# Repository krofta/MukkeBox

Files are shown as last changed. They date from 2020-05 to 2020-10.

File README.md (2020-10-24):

# MukkeBox_Electric

This is a project made with KiCAD.
During corona virus i was pretty bored at home and started to build my own portable bluetooth speaker and this is the result.
Additional I have to more repositories for software and mechanics:  
https://github.com/krofta/MukkeBox_Mechanic  
https://github.com/krofta/MukkeBox_Software

This PCB contains:  
Charger for 1-6s LiPo Packs (configured for 4s)  TI BQ24610  
ST microcontroller to controll the whole circuit STM32F030C6Tx  
Step up to make 4s pack-voltage to constant 24V TI TPS40210
Digital audio processor ST TDA7719 with i2c interface  
2x Class D audio amplifiers TI TPA3116D2  (in 2.1 sound system configuration with 20dB gain)

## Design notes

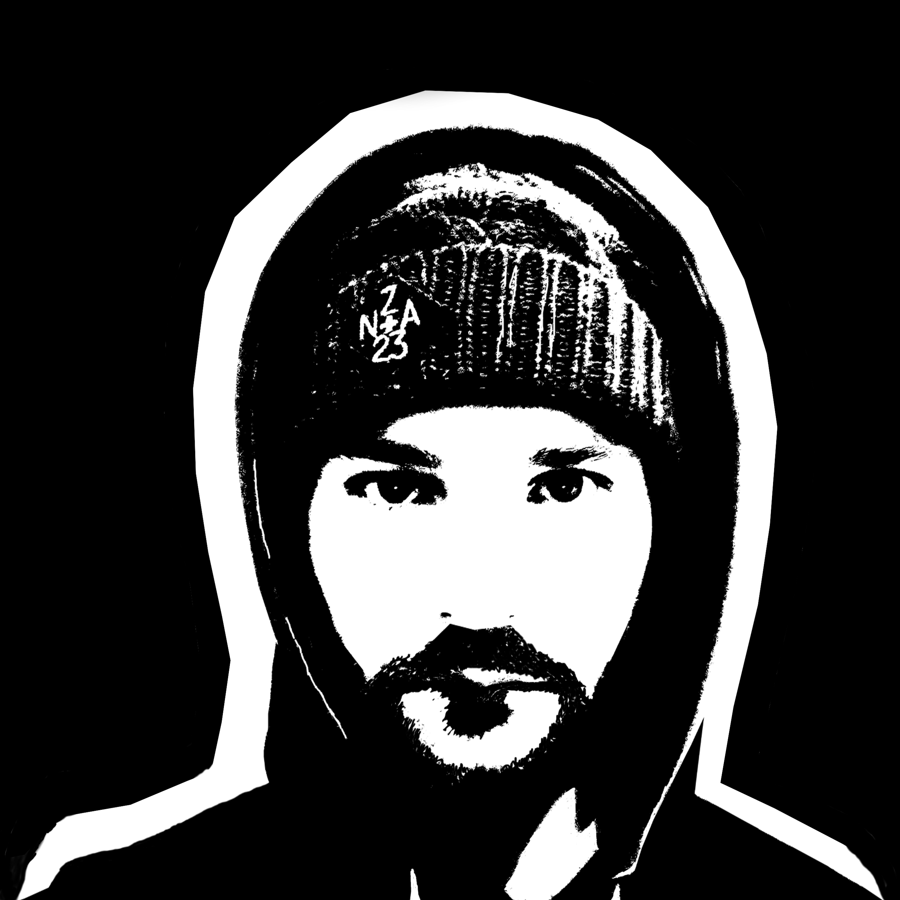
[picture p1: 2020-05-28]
IMG_50x50final.jpg

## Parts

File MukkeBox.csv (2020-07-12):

ID | Bezeichner | Gehäuse | Stückzahl | Bezeichnung | Anbieter und Referenz
1 | U301 | VQFN-24-1EP_4x4mm_P0.5mm_EP2.45x2.45mm_ThermalVias | 1 | BQ24610
2 | C311,C308 | C_0603_1608Metric_Pad1.05x0.95mm_HandSolder | 2 | 33n
3 | R302,R312,R310,R103,R104,R105,R307,R313,R315,R316,R318,R412,R413,R417,R501,R502,R505,R613,R614,R1,R301,R303,R304,R305,R15C301,R1C301,R3C301,R5C301,R7C301,R309,R201,R_201,R_202,R_203 | R_0603_1608Metric_Pad1.05x0.95mm_HandSolder | 34 | 100K
4 | Q309,Q201,Q305 | Diodes_PowerDI3333-8 | 3 | VS6412AE
5 | C307,C304,C310 | C_1210_3225Metric | 3 | 1u
6 | Q306,Q303,Q308,Q501,Q1,Q301 | SOT-23 | 6 | 2N7002
7 | R311,R106,R107,R108,R109,R119,R120,R121,R122,R124,R317,R415,R525,R615,R616,R618,R619,R620,R6,R205,R306,R19C301,R516 | R_0603_1608Metric_Pad1.05x0.95mm_HandSolder | 23 | 1K
8 | H101,H102,H103,H104,H105,H106 | MountingHole_3.2mm_M3_DIN965_Pad | 6 | MountingHole_Pad
9 | C101,C102,C103,C106,C107,C108,C109,C309,C501,C502,C504,C510,C541,C543,C544,C612,C602,C607,C608,C301,C204,C205,C302,C303,C305,C306,C312,C313,C15C301,C114,C115,C505,C506,C511,C512 | C_0603_1608Metric_Pad1.05x0.95mm_HandSolder | 35 | 100n
10 | C104,C105 | C_0603_1608Metric_Pad1.05x0.95mm_HandSolder | 2 | 20p
11 | C110,C111,C112,C113 | C_0603_1608Metric_Pad1.05x0.95mm_HandSolder | 4 | 10n
12 | C412,C211 | CP_Radial_D5.0mm_P2.50mm | 2 | 68u
13 | C507,C517,C518,C534 | C_Rect_L7.0mm_W2.5mm_P5.00mm | 4 | 1n
14 | C519,C520 | C_Rect_L7.0mm_W2.5mm_P5.00mm | 2 | 470n
15 | C521,C522,C523,C524,C526,C527,C528,C529 | C_Rect_L7.0mm_W2.5mm_P5.00mm | 8 | 220n
16 | C530,C531,C532,C_5_2,C525 | CP_Radial_D12.5mm_P5.00mm | 5 | 560u 50V
17 | D101 | LED_D3.0mm | 1 | LED_Small
18 | HS302 | Heatsink_AAVID_573300D00010G_TO-263 | 1 | 573300D00000G
19 | J101 | PinHeader_2x20_P2.54mm_Vertical | 1 | Conn_02x20_Odd_Even
20 | J102 | PinHeader_1x04_P2.54mm_Vertical | 1 | Conn_01x04
21 | J103,J104 | PinHeader_2x05_P2.54mm_Vertical | 2 | Conn_02x05_Odd_Even
22 | J301,J302 | PinHeader_2x04_P2.54mm_Vertical | 2 | Conn_02x04_Odd_Even
23 | J401 | TerminalBlock_RND_205-00045_1x02_P5.00mm_Horizontal | 1 | TB001-500-02BE CUI_Devices
24 | J501,J303 | TerminalBlock_RND_205-00047_1x04_P5.00mm_Horizontal | 2 | TB001-500-04BE CUI_Devices
25 | J602,J604,J605 | PinHeader_1x02_P2.54mm_Vertical | 3 | Conn_02x01
26 | J603 | PinHeader_2x06_P2.54mm_Vertical | 1 | Conn_02x06_Odd_Even
27 | L501,L502,L503,L504 | L_Radial_D12.0mm_P6.00mm_MuRATA_1900R | 4 | 22uH 6100-220K-RC
28 | Q307 | SOT-23 | 1 | BSS84
29 | R101,R102,R9C301 | R_0603_1608Metric_Pad1.05x0.95mm_HandSolder | 3 | 2K2
30 | R117,R118,R314,R416,R513,R518,R_FBT601,R3,R520,R521,R522,R527,R6C301,R8C301 | R_0603_1608Metric_Pad1.05x0.95mm_HandSolder | 14 | 10K
31 | R503,R203,R204 | R_0603_1608Metric_Pad1.05x0.95mm_HandSolder | 3 | 22R
32 | R504 | R_0603_1608Metric_Pad1.05x0.95mm_HandSolder | 1 | 39K
33 | R506,R507 | R_1206_3216Metric_Pad1.42x1.75mm_HandSolder | 2 | 22R
34 | R508,R509,R510,R511 | R_1206_3216Metric_Pad1.42x1.75mm_HandSolder | 4 | 8R
35 | R512,R519,R4,R5 | R_1206_3216Metric_Pad1.42x1.75mm_HandSolder | 4 | 0R
36 | R514,R610 | R_0603_1608Metric_Pad1.05x0.95mm_HandSolder | 2 | 100R
37 | R515,R526,R617 | R_0603_1608Metric_Pad1.05x0.95mm_HandSolder | 3 | DNP
38 | R523,R524 | R_0603_1608Metric_Pad1.05x0.95mm_HandSolder | 2 | 47R
39 | R602,R609 | R_0603_1608Metric_Pad1.05x0.95mm_HandSolder | 2 | 470K
40 | R_2,R2 | R_0603_1608Metric_Pad1.05x0.95mm_HandSolder | 2 | 47K
41 | R_3 | R_0603_1608Metric_Pad1.05x0.95mm_HandSolder | 1 | 422R
42 | SW501 | DIP-4_W8.89mm_SMDSocket_LongPads | 1 | DS04-254-2-02BK-SMT
43 | U101 | TO-92_Inline | 1 | LM35-LP
44 | U102 | LQFP-48_7x7mm_P0.5mm | 1 | STM32F030C6Tx_MukkeBox
45 | U503 | TSSOP-28_4.4x9.7mm_P0.65mm | 1 | TDA7719
46 | Y101 | Crystal_SMD_HC49-SD | 1 | FOXSDLF/080-20
47 | C413,C414,C411,C503,C508,C509,C536,C542,C601,C611 | CP_Radial_D4.0mm_P2.00mm | 10 | 10u
48 | F301 | Fuseholder_Cylinder-5x20mm_Schurter_0031_8201_Horizontal_Open | 1 | Fuse_Small
49 | L601,L505 | L_Bourns-SRN4018 | 2 | 10u Bourns SRN4018
50 | U602,U505 | SOT-23-6_Handsoldering | 2 | JW5026
51 | C537,C538,C539,C540,C603,C604,C605,C606,C609,C610,C613,C533,C535 | C_Rect_L7.2mm_W3.5mm_P5.00mm_FKS2_FKP2_MKS2_MKP2 | 13 | 1u
52 | J601 | PinHeader_1x03_P2.54mm_Vertical | 1 | Conn_01x03_Female
53 | TP501,TP502,TP503 | TestPoint_Pad_1.0x1.0mm | 3 | TestPoint
54 | U504 | TSOT-23-6 | 1 | AP2553AW6-7
55 | C203 | C_0603_1608Metric_Pad1.05x0.95mm_HandSolder | 1 | 100p
56 | C206 | C_0603_1608Metric_Pad1.05x0.95mm_HandSolder | 1 | 470p
57 | C207,C209 | C_1206_3216Metric | 2 | 330n
58 | C208 | C_0603_1608Metric_Pad1.05x0.95mm_HandSolder | 1 | 1u
59 | C210 | C_0603_1608Metric_Pad1.05x0.95mm_HandSolder | 1 | 220p
60 | L302 | L_Wuerth_HCI-1050 | 1 | 10u Würth 7443251000
61 | R202 | R_0603_1608Metric_Pad1.05x0.95mm_HandSolder | 1 | 20K
62 | U203 | MSOP-10-1EP_3x3mm_P0.5mm_EP1.68x1.88mm | 1 | TPS40210
63 | C314 | C_0603_1608Metric_Pad1.05x0.95mm_HandSolder | 1 | 22p
64 | D201 | TO-277B | 1 | PS1060L
65 | D301,D601 | SOT-23 | 2 | BAT54C
66 | Q302,Q304,Q310,Q311 | Diodes_PowerDI3333-8 | 4 | HSBB3103
67 | R308 | R_0603_1608Metric_Pad1.05x0.95mm_HandSolder | 1 | 10R
68 | R2C301 | R_0603_1608Metric_Pad1.05x0.95mm_HandSolder | 1 | 700K
69 | R4C301 | R_0603_1608Metric_Pad1.05x0.95mm_HandSolder | 1 | 22K
70 | R9C302 | R_0603_1608Metric_Pad1.05x0.95mm_HandSolder | 1 | 6K8
71 | RAC301,RSR301 | R_1206_3216Metric_Pad1.42x1.75mm_HandSolder | 2 | 10m
72 | U202 | StepUpModul | 1 | StepUp
73 | HS501 | Heatsink_57.9x36.8mm_4xFixation3.17mm_537-95AB | 1 | 537-95AB
74 | L301 | PQ2617BHA-330K | 1 | 22uH PQ2617BHA-220K
75 | U501 | ST_PowerSSO-36_TDA7498 | 1 | TDA7498L
76 | U502 | BK8000L | 1 | BK8000L
77 | C514,C515 | C_1210_3225Metric | 2 | 2.2u
78 | R601 | R_0603_1608Metric_Pad1.05x0.95mm_HandSolder | 1 | 3K3
79 | U103 | TO-92_Inline | 1 | MCP9700
80 | L201 | TAITEC TMPC1265HP-220MG-D | 1 | 22uH TAITEC TMPC1265HP-220MG-D
81 | REF** | WEEE-Logo_4.2x6mm_SilkScreen | 1 | WEEE-Logo_4.2x6mm_SilkScreen
82 | REF** | Symbol_KiCAD-Logo_CopperAndSilkScreenTop | 1 | KiCAD Logo
83 | R_8 | R_2512_6332Metric_Pad1.52x3.35mm_HandSolder | 1 | R012
84 | RV_1 | Potentiometer_P250 | 1 | 10K

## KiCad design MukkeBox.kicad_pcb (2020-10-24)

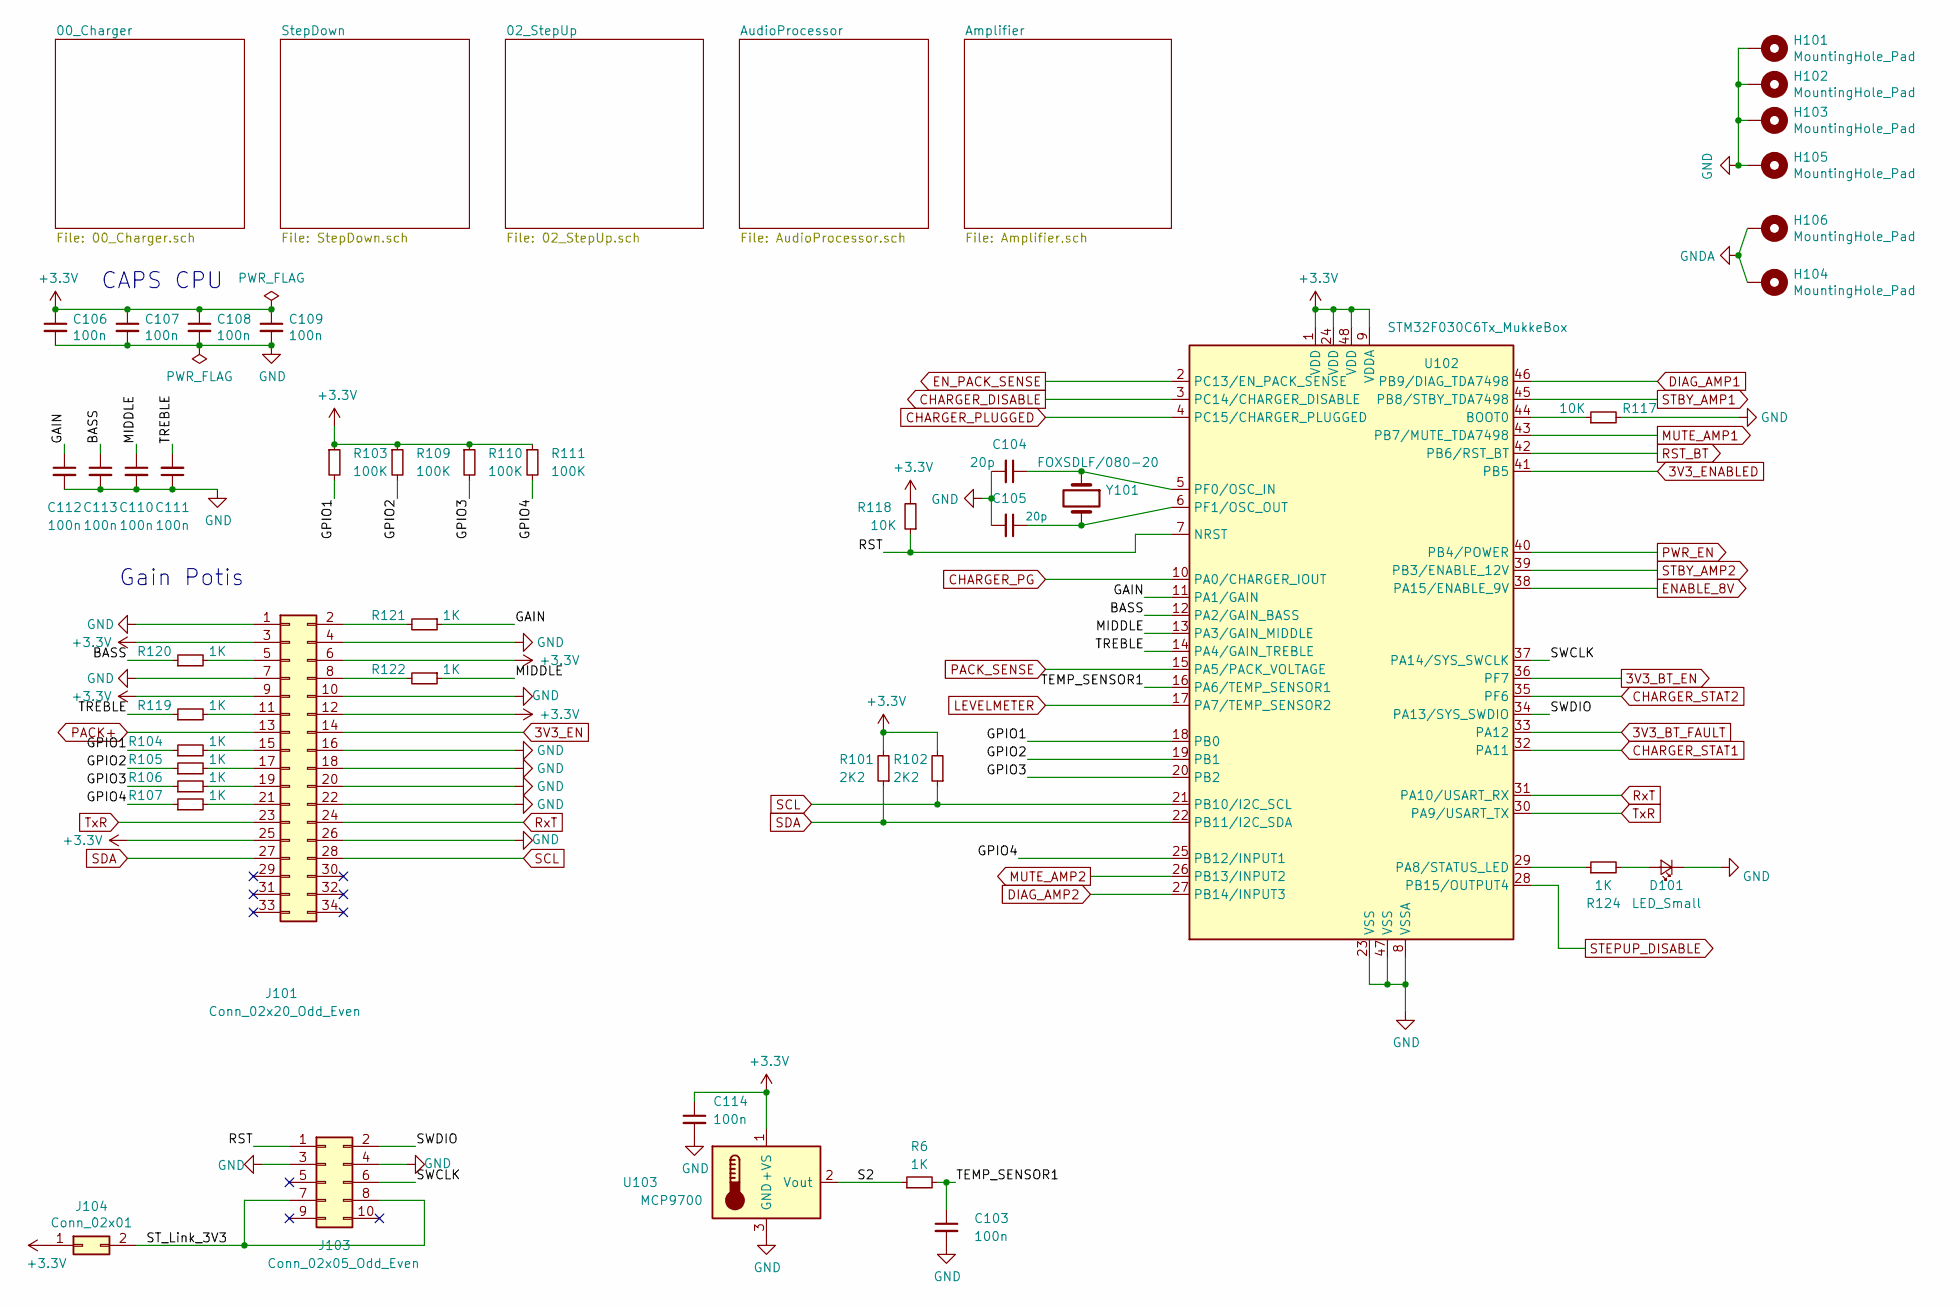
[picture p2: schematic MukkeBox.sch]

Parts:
C103, C106, C107, C108, C109, C110, C111, C112, C113, C114: 100n; C_0603_1608Metric_Pad1.05x0.95mm_HandSolder
C104, C105: 20p; C_0603_1608Metric_Pad1.05x0.95mm_HandSolder
D101: LED_Small; LED_D3.0mm
H101, H102, H103, H104, H105, H106: MountingHole_Pad; MountingHole_3.2mm_M3_DIN965_Pad
J101: Conn_02x20_Odd_Even; PinHeader_2x17_P2.54mm_Vertical
J103: Conn_02x05_Odd_Even; PinHeader_2x05_P2.54mm_Vertical
J104: Conn_02x01; PinHeader_1x02_P2.54mm_Vertical
R6, R104, R105, R106, R107, R119, R120, R121, R122, R124: 1K; R_0603_1608Metric_Pad1.05x0.95mm_HandSolder
R101, R102: 2K2; R_0603_1608Metric_Pad1.05x0.95mm_HandSolder
R103, R109, R110, R111: 100K; R_0603_1608Metric_Pad1.05x0.95mm_HandSolder
R117, R118: 10K; R_0603_1608Metric_Pad1.05x0.95mm_HandSolder
U102: STM32F030C6Tx_MukkeBox; LQFP-48_7x7mm_P0.5mm
U103: MCP9700; TO-92_Inline
Y101: FOXSDLF/080-20; Crystal_SMD_HC49-SD

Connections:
3V3_BT_EN: U102.36 (PF7); also elsewhere on the board
3V3_BT_FAULT: U102.33 (PA12); also elsewhere on the board
3V3_EN: J101.14; also elsewhere on the board
3V3_ENABLED: U102.41 (PB5); also elsewhere on the board
/BASS: C113.1, R120.1, U102.12 (PA2/GAIN_BASS)
/GAIN: C112.1, R121.1, U102.11 (PA1/GAIN)
/GPIO1: R103.2, R104.1, U102.18 (PB0)
/GPIO2: R105.1, R109.2, U102.19 (PB1)
/GPIO3: R106.1, R110.2, U102.20 (PB2)
/GPIO4: R107.1, R111.2, U102.25 (PB12/INPUT1)
/MIDDLE: C110.1, R122.1, U102.13 (PA3/GAIN_MIDDLE)
/RST: J103.1, R118.1, U102.7 (NRST)
/S2: R6.1, U103.2 (Vout)
/ST_Link_3V3: J103.7, J103.8, J104.2
/SWCLK: J103.6, U102.37 (PA14/SYS_SWCLK)
/SWDIO: J103.2, U102.34 (PA13/SYS_SWDIO)
/TEMP_SENSOR1: C103.1, R6.2, U102.16 (PA6/TEMP_SENSOR1)
/TREBLE: C111.2, R119.1, U102.14 (PA4/GAIN_TREBLE)
CHARGER_DISABLE: U102.3 (PC14/CHARGER_DISABLE); also elsewhere on the board
CHARGER_PG: U102.10 (PA0/CHARGER_IOUT); also elsewhere on the board
CHARGER_PLUGGED: U102.4 (PC15/CHARGER_PLUGGED); also elsewhere on the board
CHARGER_STAT1: U102.32 (PA11); also elsewhere on the board
CHARGER_STAT2: U102.35 (PF6); also elsewhere on the board
DIAG_AMP1: U102.46 (PB9/DIAG_TDA7498); also elsewhere on the board
DIAG_AMP2: U102.27 (PB14/INPUT3); also elsewhere on the board
ENABLE_8V: U102.38 (PA15/ENABLE_9V); also elsewhere on the board
EN_PACK_SENSE: U102.2 (PC13/EN_PACK_SENSE); also elsewhere on the board
GND: C103.2, C104.2, C105.2, C106.2, C107.2, C108.2, C109.2, C110.2, C111.1, C112.2, C113.2, C114.2, D101.1 (K), H101.1, H102.1, H103.1, H105.1, J101.1, J101.4, J101.7, J101.10, J101.16, J101.18, J101.20, J101.22, J101.26, J103.3, J103.4, R117.2, U102.8 (VSSA), U102.23 (VSS), U102.47 (VSS), U103.3 (GND); also elsewhere on the board
GNDA: H104.1, H106.1; also elsewhere on the board
LEVELMETER: U102.17 (PA7/TEMP_SENSOR2); also elsewhere on the board
MUTE_AMP1: U102.43 (PB7/MUTE_TDA7498); also elsewhere on the board
MUTE_AMP2: U102.26 (PB13/INPUT2); also elsewhere on the board
unnamed: C104.1, U102.5 (PF0/OSC_IN), Y101.1
unnamed: C105.1, U102.6 (PF1/OSC_OUT), Y101.2
unnamed: D101.2 (A), R124.2
unnamed: J101.2, R121.2
unnamed: J101.5, R120.2
unnamed: J101.8, R122.2
unnamed: J101.11, R119.2
unnamed: J101.15, R104.2
unnamed: J101.17, R105.2
unnamed: J101.19, R106.2
unnamed: J101.21, R107.2
unnamed: R117.1, U102.44 (BOOT0)
unnamed: R124.1, U102.29 (PA8/STATUS_LED)
PACK+: J101.13; also elsewhere on the board
PACK_SENSE: U102.15 (PA5/PACK_VOLTAGE); also elsewhere on the board
PWR_EN: U102.40 (PB4/POWER); also elsewhere on the board
RST_BT: U102.42 (PB6/RST_BT); also elsewhere on the board
RxT: J101.24, U102.31 (PA10/USART_RX); also elsewhere on the board
SCL: J101.28, R102.1, U102.21 (PB10/I2C_SCL); also elsewhere on the board
SDA: J101.27, R101.1, U102.22 (PB11/I2C_SDA); also elsewhere on the board
STBY_AMP1: U102.45 (PB8/STBY_TDA7498); also elsewhere on the board
STBY_AMP2: U102.39 (PB3/ENABLE_12V); also elsewhere on the board
STEPUP_DISABLE: U102.28 (PB15/OUTPUT4); also elsewhere on the board
TxR: J101.23, U102.30 (PA9/USART_TX); also elsewhere on the board

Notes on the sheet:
Gain Potis
CAPS CPU

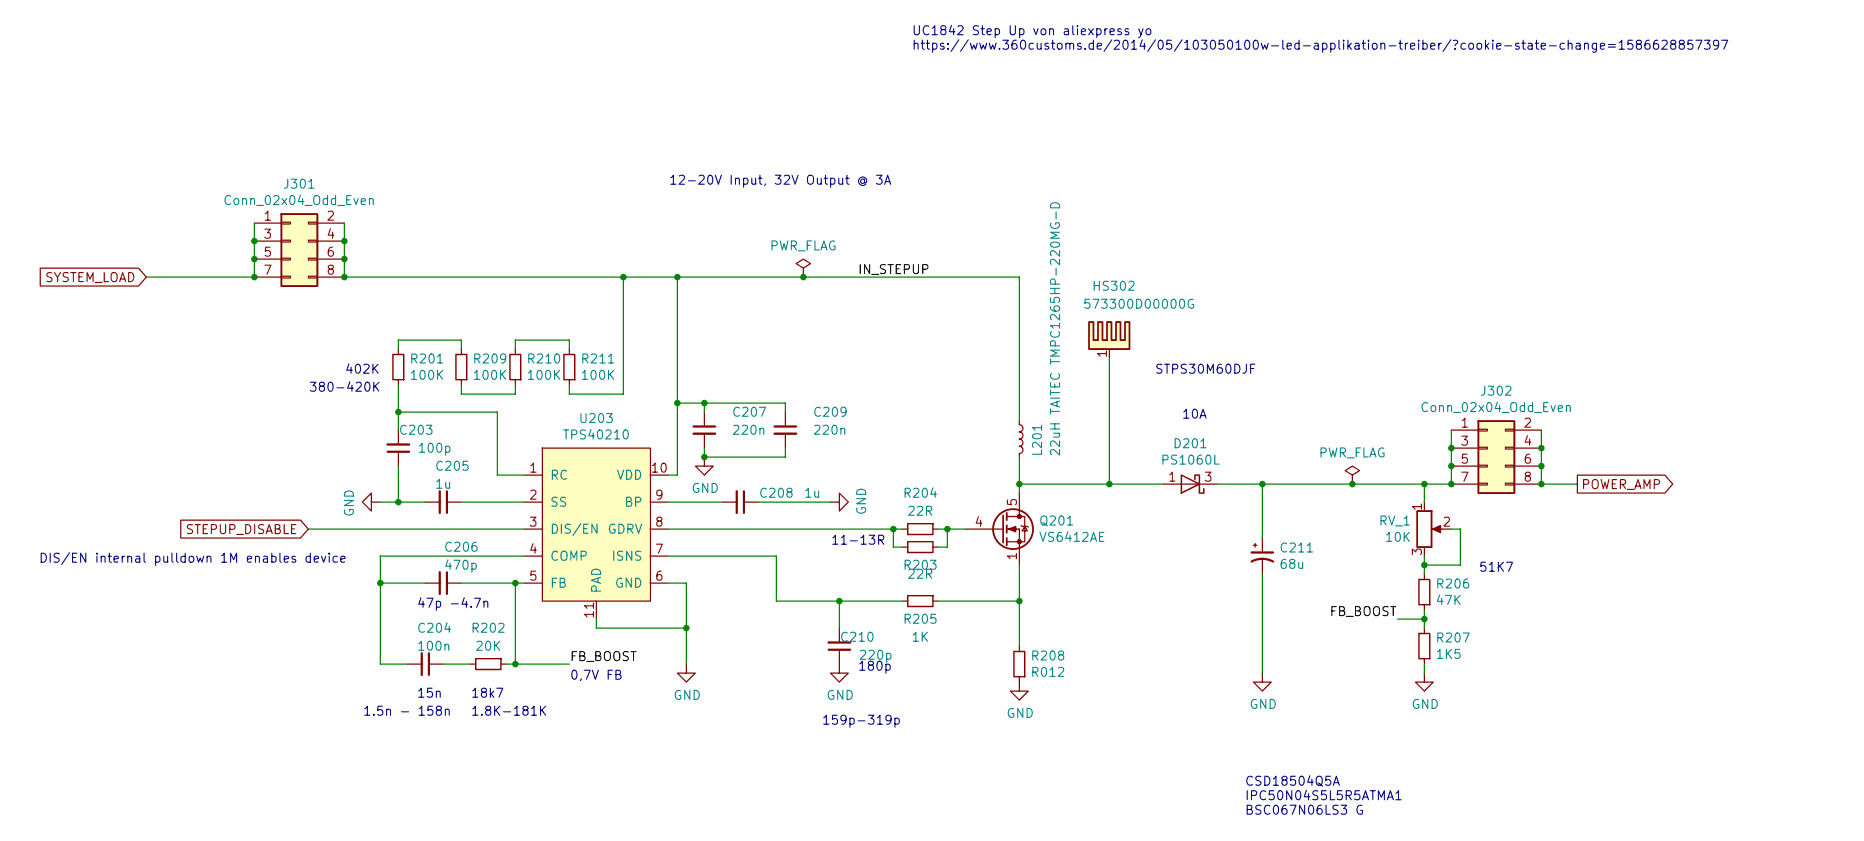
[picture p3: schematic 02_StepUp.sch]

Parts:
C203: 100p; C_0603_1608Metric_Pad1.05x0.95mm_HandSolder
C204: 100n; C_0603_1608Metric_Pad1.05x0.95mm_HandSolder
C205, C208: 1u; C_0603_1608Metric_Pad1.05x0.95mm_HandSolder
C206: 470p; C_0603_1608Metric_Pad1.05x0.95mm_HandSolder
C207, C209: 220n; C_0603_1608Metric_Pad1.05x0.95mm_HandSolder
C210: 220p; C_0603_1608Metric_Pad1.05x0.95mm_HandSolder
C211: 68u; CP_Radial_D5.0mm_P2.50mm
D201: PS1060L; TO-277B
HS302: 573300D00000G; Heatsink_AAVID_573300D00010G_TO-263
J301, J302: Conn_02x04_Odd_Even; PinHeader_2x04_P2.54mm_Vertical
L201: 22uH TAITEC TMPC1265HP-220MG-D; TAITEC TMPC1265HP-220MG-D
Q201: VS6412AE; Diodes_PowerDI3333-8
R201, R209, R210, R211: 100K; R_0603_1608Metric_Pad1.05x0.95mm_HandSolder
R202: 20K; R_0603_1608Metric_Pad1.05x0.95mm_HandSolder
R203, R204: 22R; R_0603_1608Metric_Pad1.05x0.95mm_HandSolder
R205: 1K; R_0603_1608Metric_Pad1.05x0.95mm_HandSolder
R206: 47K; R_0603_1608Metric_Pad1.05x0.95mm_HandSolder
R207: 1K5; R_0603_1608Metric_Pad1.05x0.95mm_HandSolder
R208: R012; R_2512_6332Metric_Pad1.52x3.35mm_HandSolder
RV_1: 10K; Potentiometer_P250
U203: TPS40210; MSOP-10-1EP_3x3mm_P0.5mm_EP1.68x1.88mm

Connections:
/02_StepUp/FB_BOOST: C206.1, R202.1, R206.1, R207.2, U203.5 (FB)
/02_StepUp/IN_STEPUP: C207.1, C209.1, J301.2, J301.4, J301.6, J301.8, L201.1, R211.1, U203.10 (VDD)
GND: C203.1, C205.2, C207.2, C208.1, C209.2, C210.1, C211.2, R207.1, R208.1, U203.6 (GND), U203.11 (PAD); also elsewhere on the board
unnamed: C203.2, R201.1, U203.1 (RC)
unnamed: C204.1, R202.2
unnamed: C204.2, C206.2, U203.4 (COMP)
unnamed: C205.1, U203.2 (SS)
unnamed: C208.2, U203.9 (BP)
unnamed: C210.2, R205.2, U203.7 (ISNS)
unnamed: C211.1, D201.3 (K), J302.1, J302.3, J302.5, J302.7, RV_1.1
unnamed: D201.1 (A), D201.2 (A), HS302.1, L201.2, Q201.5 (D)
unnamed: Q201.1 (S), Q201.2 (S), Q201.3 (S), R205.1, R208.2
unnamed: Q201.4 (G), R203.2, R204.1
unnamed: R201.2, R209.2
unnamed: R203.1, R204.2, U203.8 (GDRV)
unnamed: R206.2, RV_1.2, RV_1.3
unnamed: R209.1, R210.1
unnamed: R210.2, R211.2
POWER_AMP: J302.2, J302.4, J302.6, J302.8; also elsewhere on the board
STEPUP_DISABLE: U203.3 (DIS/EN); also elsewhere on the board
SYSTEM_LOAD: J301.1, J301.3, J301.5, J301.7; also elsewhere on the board

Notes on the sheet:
UC1842 Step Up von aliexpress yo https://www.360customs.de/2014/05/103050100w-led-applikation-treiber/?cookie-state-change=1586628857397
DIS/EN internal pulldown 1M enables device
12-20V Input, 32V Output @ 3A
51K7
18k7
15n
402K
180p
10A
47p -4.7n
1.5n - 158n
1.8K-181K
159p-319p
11-13R
380-420K
CSD18504Q5A IPC50N04S5L5R5ATMA1 BSC067N06LS3 G
STPS30M60DJF
0,7V FB

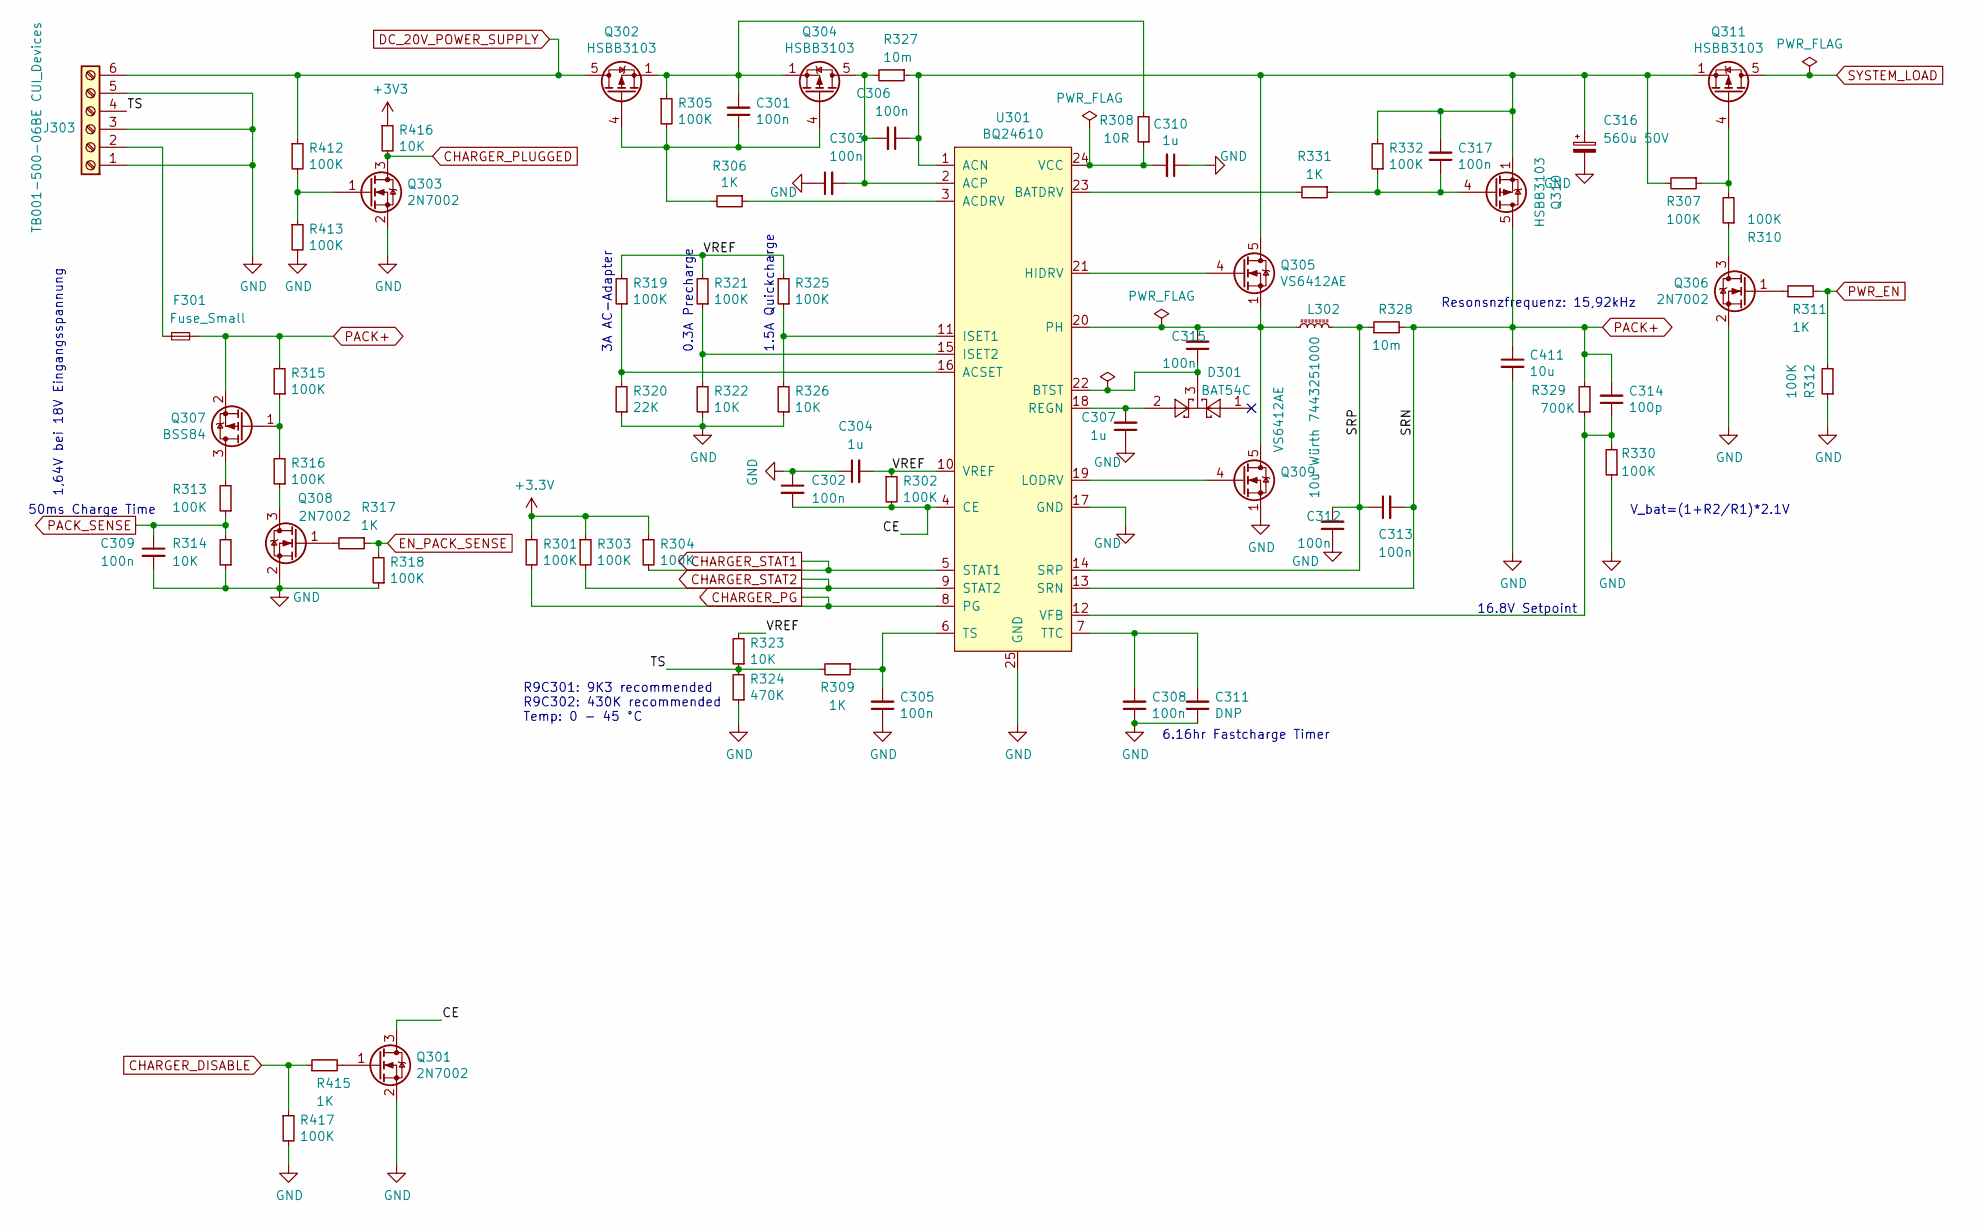
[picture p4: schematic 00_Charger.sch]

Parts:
C301, C302, C303, C305, C306, C308, C309, C312, C313, C315, C317: 100n; C_0603_1608Metric_Pad1.05x0.95mm_HandSolder
C304, C307, C310: 1u; C_1210_3225Metric
C311: DNP; C_0603_1608Metric_Pad1.05x0.95mm_HandSolder
C314: 100p; C_0603_1608Metric_Pad1.05x0.95mm_HandSolder
C316: 560u 50V; CP_Radial_D12.5mm_P5.00mm
C411: 10u; C_1206_3216Metric_Pad1.42x1.75mm_HandSolder
D301: BAT54C; SOT-23
F301: Fuse_Small; Fuseholder_Cylinder-5x20mm_Schurter_0031_8201_Horizontal_Op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
J303: TB001-500-06BE CUI_Devices; TerminalBlock_RND_205-00049_1x06_P5.00mm_Horizontal
L302: 10u Würth 7443251000; L_Wuerth_HCI-1050
Q301, Q303, Q306, Q308: 2N7002; SOT-23
Q302, Q304, Q310, Q311: HSBB3103; Diodes_PowerDI3333-8
Q305, Q309: VS6412AE; Diodes_PowerDI3333-8
Q307: BSS84; SOT-23
R301, R302, R303, R304, R305, R307, R310, R312, R313, R315, R316, R318, R319, R321, R325, R330, R332, R412, R413, R417: 100K; R_0603_1608Metric_Pad1.05x0.95mm_HandSolder
R306, R309, R311, R317, R331, R415: 1K; R_0603_1608Metric_Pad1.05x0.95mm_HandSolder
R308: 10R; R_0603_1608Metric_Pad1.05x0.95mm_HandSolder
R314, R322, R323, R326, R416: 10K; R_0603_1608Metric_Pad1.05x0.95mm_HandSolder
R320: 22K; R_0603_1608Metric_Pad1.05x0.95mm_HandSolder
R324: 470K; R_0603_1608Metric_Pad1.05x0.95mm_HandSolder
R327, R328: 10m; R_1206_3216Metric_Pad1.42x1.75mm_HandSolder
R329: 700K; R_0603_1608Metric_Pad1.05x0.95mm_HandSolder
U301: BQ24610; VQFN-24-1EP_4x4mm_P0.5mm_EP2.45x2.45mm_ThermalVias

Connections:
/00_Charger/CE: C302.2, Q301.3 (D), R302.2, U301.4 (CE)
/00_Charger/SRP: C312.2, C313.1, L302.2, R328.1, U301.14 (SRP)
/00_Charger/TS: J303.4, R309.2, R323.1, R324.2
/00_Charger/VREF: C304.2, R302.1, R319.2, R321.2, R323.2, R325.2, U301.10 (VREF)
CHARGER_DISABLE: R415.1, R417.1; also elsewhere on the board
CHARGER_PG: R301.2, U301.8 (PG); also elsewhere on the board
CHARGER_PLUGGED: Q303.3 (D), R416.2; also elsewhere on the board
CHARGER_STAT1: R304.2, U301.5 (STAT1); also elsewhere on the board
CHARGER_STAT2: R303.2, U301.9 (STAT2); also elsewhere on the board
DC_20V_POWER_SUPPLY: J303.6, Q302.5 (D), R412.1; also elsewhere on the board
EN_PACK_SENSE: R317.1, R318.2; also elsewhere on the board
GND: C302.1, C303.1, C304.1, C305.1, C307.1, C308.1, C309.2, C310.1, C311.1, C312.1, C316.2, C411.2, J303.1, J303.3, J303.5, Q301.2 (S), Q303.2 (S), Q306.2 (S), Q308.2 (S), Q309.1 (S), Q309.2 (S), Q309.3 (S), R312.1, R314.1, R318.1, R320.1, R322.1, R324.1, R326.1, R330.1, R413.2, R417.2, U301.17 (GND), U301.25 (GND); also elsewhere on the board
unnamed: C301.1, Q302.4 (G), Q304.4 (G), R305.2, R306.2
unnamed: C301.2, Q302.1 (S), Q302.2 (S), Q302.3 (S), Q304.1 (S), Q304.2 (S), Q304.3 (S), R305.1, R308.2
unnamed: C303.2, C306.2, Q304.5 (D), R327.2, U301.2 (ACP)
unnamed: C305.2, R309.1, U301.6 (TS)
unnamed: C306.1, C316.1, C317.2, Q305.5 (D), Q310.1 (S), Q310.2 (S), Q310.3 (S), Q311.1 (S), Q311.2 (S), Q311.3 (S), R307.2, R327.1, R332.2, U301.1 (ACN)
unnamed: C307.2, D301.2, U301.18 (REGN)
unnamed: C308.2, C311.2, U301.7 (TTC)
unnamed: C310.2, R308.1, U301.24 (VCC)
unnamed: C314.1, R329.1, R330.2, U301.12 (VFB)
unnamed: C315.1, D301.3, U301.22 (BTST)
unnamed: C315.2, L302.1, Q305.1 (S), Q305.2 (S), Q305.3 (S), Q309.5 (D), U301.20 (PH)
unnamed: C317.1, Q310.4 (G), R331.1, R332.1
unnamed: F301.1, J303.2
unnamed: Q301.1 (G), R415.2
unnamed: Q303.1 (G), R412.2, R413.1
unnamed: Q305.4 (G), U301.21 (HIDRV)
unnamed: Q306.1 (G), R311.1
unnamed: Q306.3 (D), R310.1
unnamed: Q307.1 (G), R315.1, R316.2
unnamed: Q307.3 (D), R313.2
unnamed: Q308.1 (G), R317.2
unnamed: Q308.3 (D), R316.1
unnamed: Q309.4 (G), U301.19 (LODRV)
unnamed: Q311.4 (G), R307.1, R310.2
unnamed: R306.1, U301.3 (ACDRV)
unnamed: R319.1, R320.2, U301.16 (ACSET)
unnamed: R321.1, R322.2, U301.15 (ISET2)
unnamed: R325.1, R326.2, U301.11 (ISET1)
unnamed: R331.2, U301.23 (BATDRV)
PACK+: C313.2, C314.2, C411.1, F301.2, Q307.2 (S), Q310.5 (D), R315.2, R328.2, R329.2, U301.13 (SRN); also elsewhere on the board
PACK_SENSE: C309.1, R313.1, R314.2; also elsewhere on the board
PWR_EN: R311.2, R312.2; also elsewhere on the board
SYSTEM_LOAD: Q311.5 (D); also elsewhere on the board

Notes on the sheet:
1,64V bei 18V Eingangsspannung
V_bat=(1+R2/R1)*2.1V
3A AC-Adapter
0.3A Precharge
1.5A Quickcharge
16.8V Setpoint
6.16hr Fastcharge Timer
Resonsnzfrequenz: 15,92kHz
50ms Charge Time
R9C301: 9K3 recommended R9C302: 430K recommended Temp: 0 - 45 °C

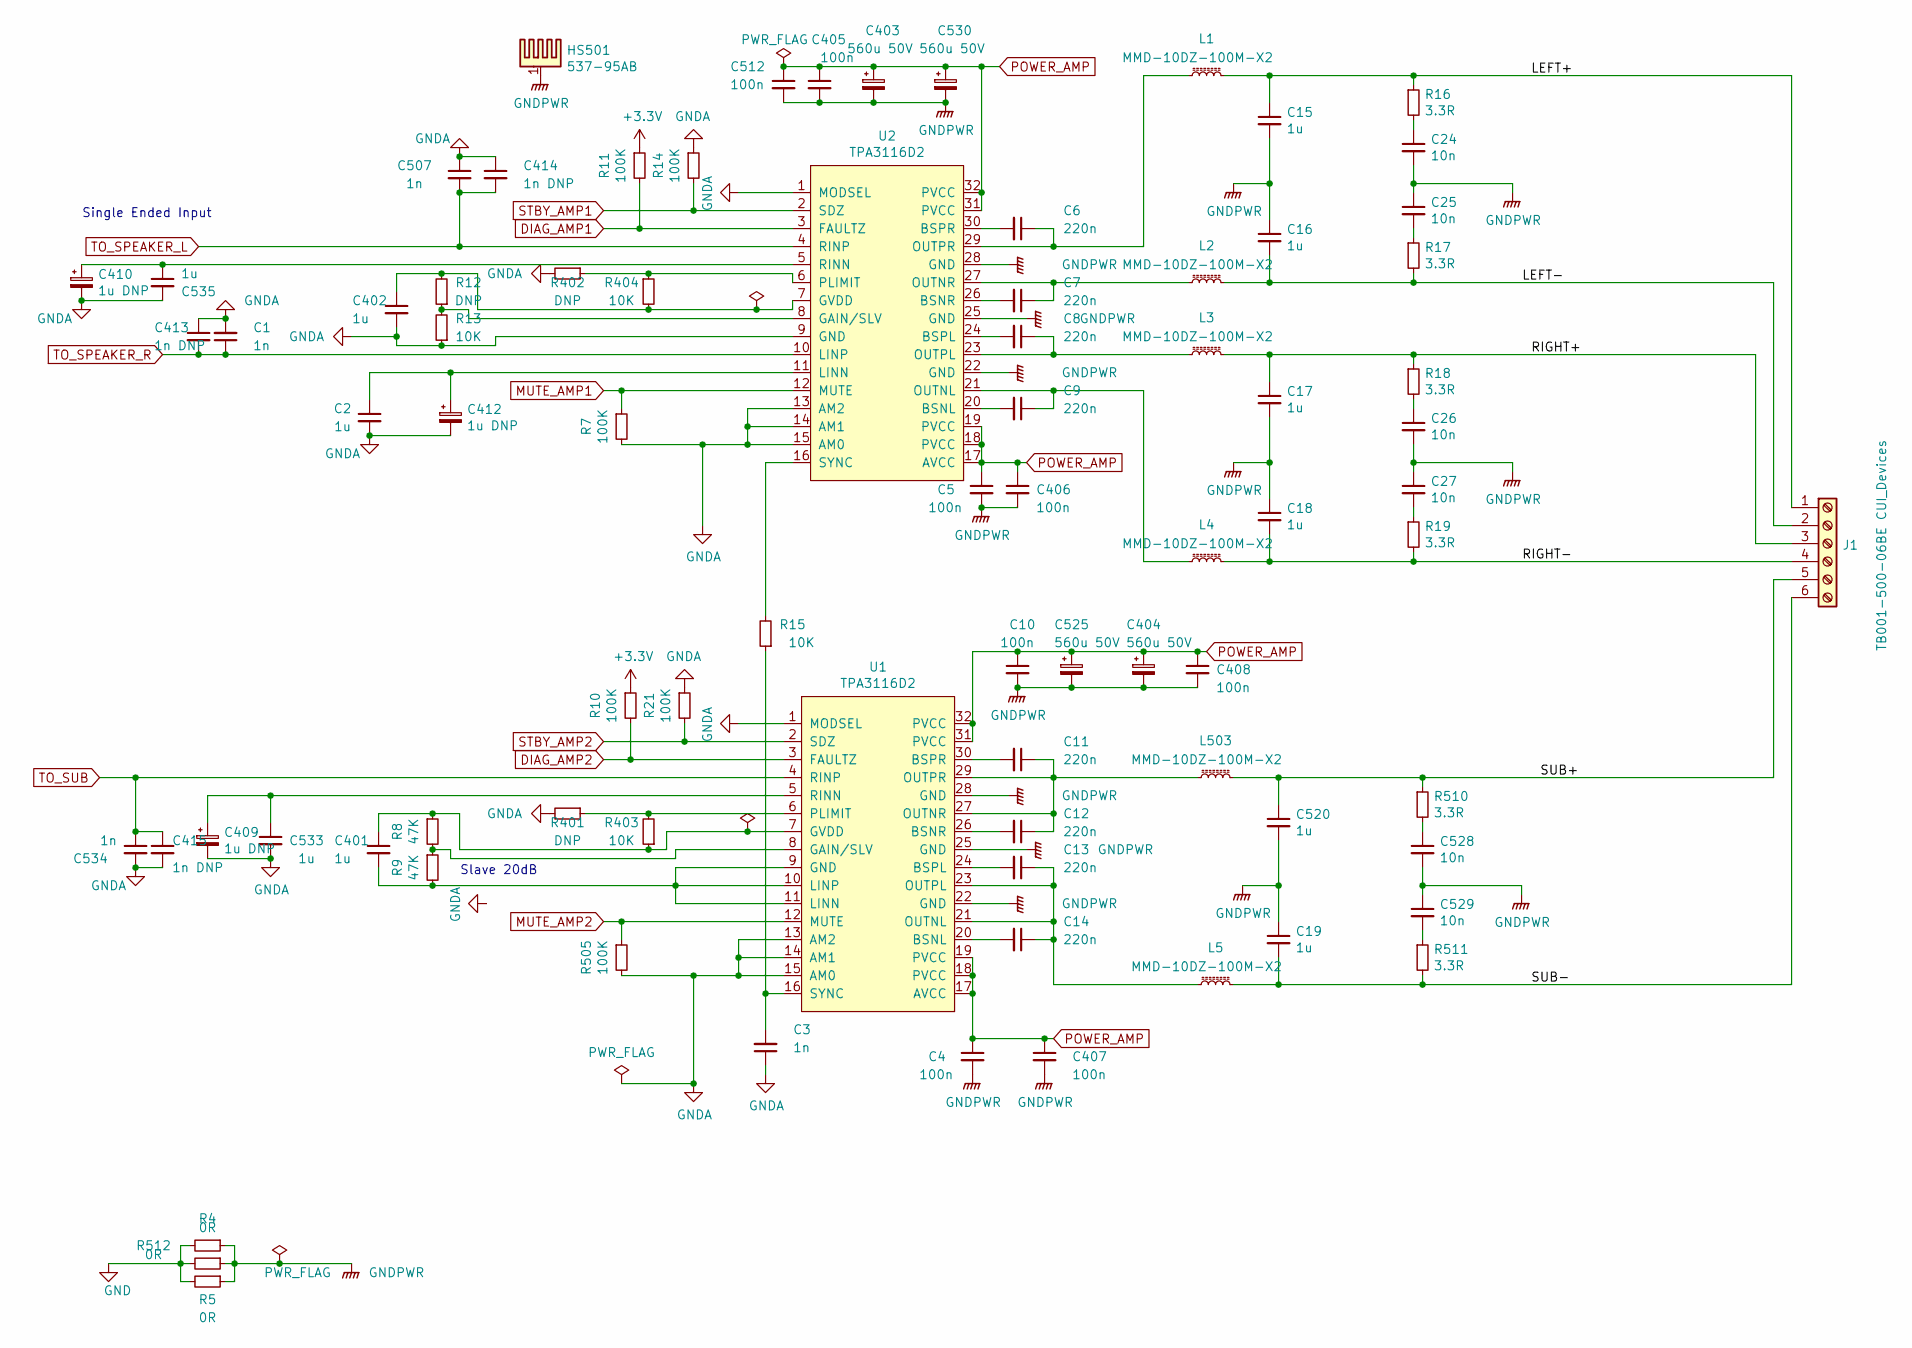
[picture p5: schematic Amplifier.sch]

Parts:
C1, C507, C534: 1n; C_Rect_L7.0mm_W2.5mm_P5.00mm
C2, C533, C535: 1u; C_Rect_L7.2mm_W3.5mm_P5.00mm_FKS2_FKP2_MKS2_MKP2
C3: 1n; C_0603_1608Metric_Pad1.05x0.95mm_HandSolder
C4, C5, C10, C405, C406, C407, C408, C512: 100n; C_0603_1608Metric_Pad1.05x0.95mm_HandSolder
C6, C7, C8, C9, C11, C12, C13, C14: 220n; C_0603_1608Metric_Pad1.05x0.95mm_HandSolder
C15, C16, C17, C18, C19, C520: 1u; C_1210_3225Metric_Pad1.42x2.65mm_HandSolder
C24, C25, C26, C27, C528, C529: 10n; C_1210_3225Metric_Pad1.42x2.65mm_HandSolder
C401, C402: 1u; C_0603_1608Metric_Pad1.05x0.95mm_HandSolder
C403, C404, C525, C530: 560u 50V; CP_Radial_D12.5mm_P5.00mm
C409, C410, C412: 1u DNP; CP_EIA-3216-18_Kemet-A
C413, C414, C415: 1n DNP; C_0603_1608Metric_Pad1.05x0.95mm_HandSolder
HS501: 537-95AB; Heatsink_57.9x36.8mm_4xFixation3.17mm_537-95AB
J1: TB001-500-06BE CUI_Devices; TerminalBlock_RND_205-00049_1x06_P5.00mm_Horizontal
L1, L2, L3, L4, L5, L503: MMD-10DZ-100M-X2; L_Wuerth_HCI-1030
R4, R5, R512: 0R; R_1206_3216Metric_Pad1.42x1.75mm_HandSolder
R7, R10, R11, R14, R21, R505: 100K; R_0603_1608Metric_Pad1.05x0.95mm_HandSolder
R8, R9: 47K; R_0603_1608Metric_Pad1.05x0.95mm_HandSolder
R12, R401, R402: DNP; R_0603_1608Metric_Pad1.05x0.95mm_HandSolder
R13, R15, R403, R404: 10K; R_0603_1608Metric_Pad1.05x0.95mm_HandSolder
R16, R17, R18, R19, R510, R511: 3.3R; R_1210_3225Metric_Pad1.42x2.65mm_HandSolder
U1, U2: TPA3116D2; HTSSOP-32-TPA3116D2

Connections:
/Amplifier/LEFT+: C15.1, J1.1, L1.2, R16.1
/Amplifier/LEFT-: C16.2, J1.2, L2.2, R17.2
/Amplifier/RIGHT+: C17.1, J1.3, L3.2, R18.1
/Amplifier/RIGHT-: C18.2, J1.4, L4.2, R19.2
/Amplifier/SUB+: C520.1, J1.5, L503.2, R510.1
/Amplifier/SUB-: C19.2, J1.6, L5.2, R511.2
DIAG_AMP1: R11.2, U2.3 (FAULTZ); also elsewhere on the board
DIAG_AMP2: R10.2, U1.3 (FAULTZ); also elsewhere on the board
GND: R4.2, R5.2, R512.2; also elsewhere on the board
GNDA: C1.2, C2.2, C3.1, C402.2, C409.2, C410.2, C412.2, C413.1, C414.1, C415.2, C507.1, C533.2, C534.2, C535.2, R7.2, R13.1, R14.1, R21.1, R401.2, R402.2, R505.2, U1.1 (MODSEL), U1.13 (AM2), U1.14 (AM1), U1.15 (AM0), U2.1 (MODSEL), U2.9 (GND), U2.13 (AM2), U2.14 (AM1), U2.15 (AM0); also elsewhere on the board
GNDPWR: C4.2, C5.2, C10.2, C15.2, C16.1, C17.2, C18.1, C19.1, C24.2, C25.1, C26.2, C27.1, C403.2, C404.2, C405.2, C406.2, C407.2, C408.2, C512.2, C520.2, C525.2, C528.2, C529.1, C530.2, HS501.1, R4.1, R5.1, R512.1, U1.22 (GND), U1.25 (GND), U1.28 (GND), U2.22 (GND), U2.25 (GND), U2.28 (GND)
MUTE_AMP1: R7.1, U2.12 (MUTE); also elsewhere on the board
MUTE_AMP2: R505.1, U1.12 (MUTE); also elsewhere on the board
unnamed: C2.1, C412.1, U2.11 (LINN)
unnamed: C3.2, R15.1, U1.16 (SYNC)
unnamed: C6.1, L1.1, U2.29 (OUTPR)
unnamed: C6.2, U2.30 (BSPR)
unnamed: C7.1, L2.1, U2.27 (OUTNR)
unnamed: C7.2, U2.26 (BSNR)
unnamed: C8.1, L3.1, U2.23 (OUTPL)
unnamed: C8.2, U2.24 (BSPL)
unnamed: C9.1, L4.1, U2.21 (OUTNL)
unnamed: C9.2, U2.20 (BSNL)
unnamed: C11.1, C12.1, L503.1, U1.27 (OUTNR), U1.29 (OUTPR)
unnamed: C11.2, U1.30 (BSPR)
unnamed: C12.2, U1.26 (BSNR)
unnamed: C13.1, C14.1, L5.1, U1.21 (OUTNL), U1.23 (OUTPL)
unnamed: C13.2, U1.24 (BSPL)
unnamed: C14.2, U1.20 (BSNL)
unnamed: C24.1, R16.2
unnamed: C25.2, R17.1
unnamed: C26.1, R18.2
unnamed: C27.2, R19.1
unnamed: C401.1, R8.1, R403.1, U1.7 (GVDD)
unnamed: C401.2, R9.2, U1.9 (GND), U1.10 (LINP), U1.11 (LINN)
unnamed: C402.1, R12.2, R404.2, U2.7 (GVDD)
unnamed: C409.1, C533.1, U1.5 (RINN)
unnamed: C410.1, C535.1, U2.5 (RINN)
unnamed: C528.1, R510.2
unnamed: C529.2, R511.1
unnamed: R8.2, R9.1, U1.8 (GAIN/SLV)
unnamed: R12.1, R13.2, U2.8 (GAIN/SLV)
unnamed: R15.2, U2.16 (SYNC)
unnamed: R401.1, R403.2, U1.6 (PLIMIT)
unnamed: R402.1, R404.1, U2.6 (PLIMIT)
POWER_AMP: C4.1, C5.1, C10.1, C403.1, C404.1, C405.1, C406.1, C407.1, C408.1, C512.1, C525.1, C530.1, U1.17 (AVCC), U1.18 (PVCC), U1.19 (PVCC), U1.31 (PVCC), U1.32 (PVCC), U2.17 (AVCC), U2.18 (PVCC), U2.19 (PVCC), U2.31 (PVCC), U2.32 (PVCC); also elsewhere on the board
STBY_AMP1: R14.2, U2.2 (SDZ); also elsewhere on the board
STBY_AMP2: R21.2, U1.2 (SDZ); also elsewhere on the board
TO_SPEAKER_L: C414.2, C507.2, U2.4 (RINP); also elsewhere on the board
TO_SPEAKER_R: C1.1, C413.2, U2.10 (LINP); also elsewhere on the board
TO_SUB: C415.1, C534.1, U1.4 (RINP); also elsewhere on the board

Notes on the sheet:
Single Ended Input
Slave 20dB

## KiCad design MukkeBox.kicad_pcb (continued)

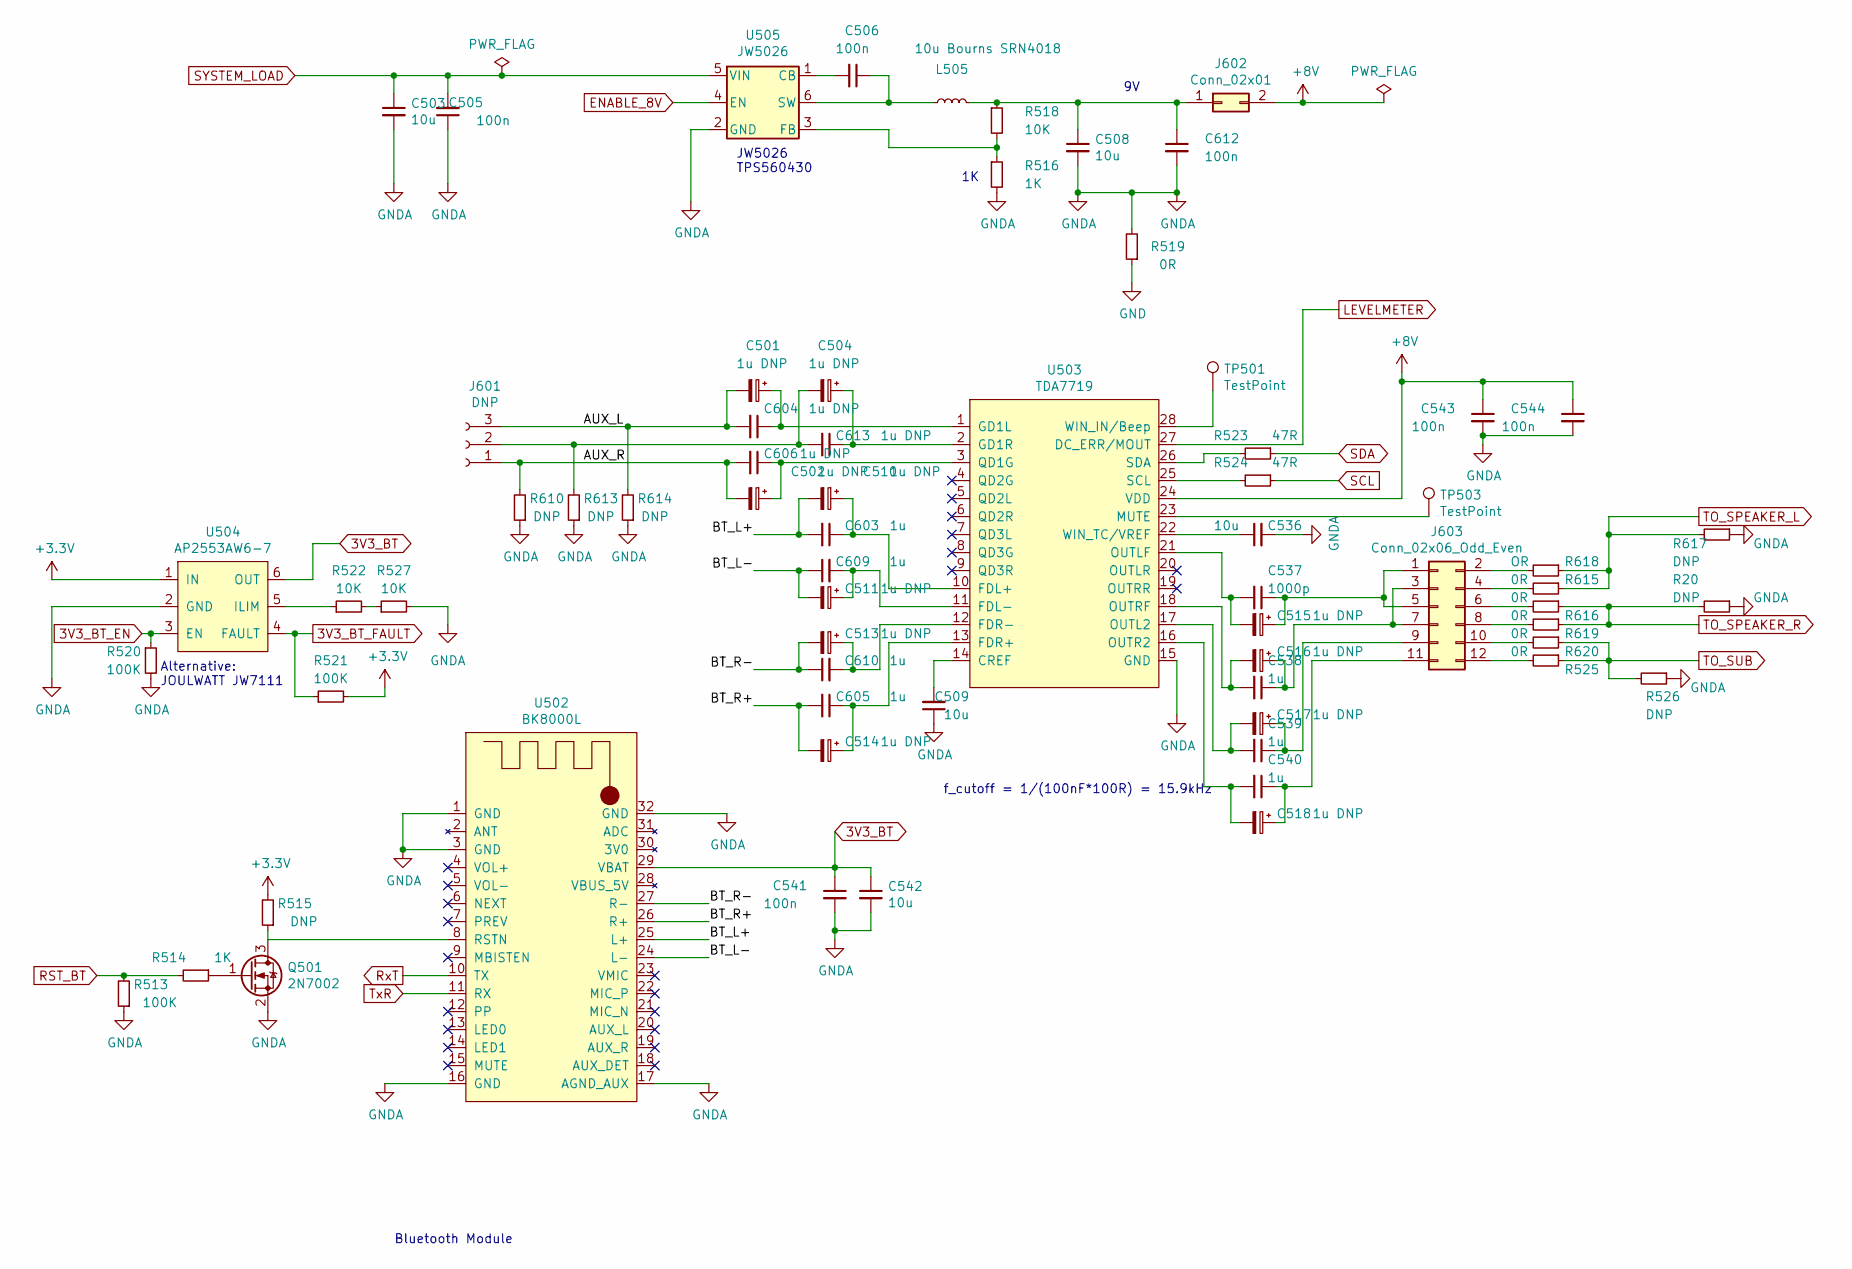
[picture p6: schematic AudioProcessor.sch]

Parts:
C501, C502, C504, C510, C511, C513, C514, C515, C516, C517, C518: 1u DNP; CP_EIA-3216-18_Kemet-A
C503, C508, C509, C536, C542: 10u; C_1206_3216Metric_Pad1.42x1.75mm_HandSolder
C505, C506, C541, C543, C544, C612: 100n; C_0603_1608Metric_Pad1.05x0.95mm_HandSolder
C537: 1000p; C_Rect_L7.2mm_W3.5mm_P5.00mm_FKS2_FKP2_MKS2_MKP2
C538, C539, C540, C603, C605, C609, C610: 1u; C_Rect_L7.2mm_W3.5mm_P5.00mm_FKS2_FKP2_MKS2_MKP2
C604, C606, C613: 1u DNP; C_Rect_L7.2mm_W3.5mm_P5.00mm_FKS2_FKP2_MKS2_MKP2
J601: DNP; PinHeader_1x03_P2.54mm_Vertical
J602: Conn_02x01; PinHeader_1x02_P2.54mm_Vertical
J603: Conn_02x06_Odd_Even; PinHeader_2x06_P2.54mm_Vertical
L505: 10u Bourns SRN4018; L_Bourns-SRN4018
Q501: 2N7002; SOT-23
R20, R515, R526, R610, R613, R614, R617: DNP; R_0603_1608Metric_Pad1.05x0.95mm_HandSolder
R513, R520, R521: 100K; R_0603_1608Metric_Pad1.05x0.95mm_HandSolder
R514, R516: 1K; R_0603_1608Metric_Pad1.05x0.95mm_HandSolder
R518, R522, R527: 10K; R_0603_1608Metric_Pad1.05x0.95mm_HandSolder
R519: 0R; R_1206_3216Metric_Pad1.42x1.75mm_HandSolder
R523, R524: 47R; R_0603_1608Metric_Pad1.05x0.95mm_HandSolder
R525, R615, R616, R619, R620: 0R; R_0603_1608Metric_Pad1.05x0.95mm_HandSolder
R618: OR; R_0603_1608Metric_Pad1.05x0.95mm_HandSolder
TP501, TP503: TestPoint; TestPoint_Pad_1.0x1.0mm
U502: BK8000L
U503: TDA7719; TSSOP-28_4.4x9.7mm_P0.65mm
U504: AP2553AW6-7; TSOT-23-6
U505: JW5026; SOT-23-6_Handsoldering

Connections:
3V3_BT: C541.1, C542.1, U502.29 (VBAT), U504.6 (OUT)
3V3_BT_EN: R520.1, U504.3 (EN); also elsewhere on the board
3V3_BT_FAULT: R521.1, U504.4 (FAULT); also elsewhere on the board
+8V: C543.1, C544.1, J602.2, U503.24 (VDD)
/AudioProcessor/AUX_L: C501.2, C604.2, J601.3, R614.2
/AudioProcessor/AUX_R: C502.2, C606.2, J601.1, R610.2
/AudioProcessor/BT_L+: C510.2, C603.2, U502.25 (L+)
/AudioProcessor/BT_L-: C511.2, C609.1, U502.24 (L-)
/AudioProcessor/BT_R+: C514.2, C605.2, U502.26 (R+)
/AudioProcessor/BT_R-: C513.2, C610.1, U502.27 (R-)
ENABLE_8V: U505.4 (EN); also elsewhere on the board
GND: R519.1; also elsewhere on the board
GNDA: C503.2, C505.1, C508.2, C509.1, C536.2, C541.2, C542.2, C543.2, C544.2, C612.2, Q501.2 (S), R20.1, R513.1, R516.2, R519.2, R520.2, R526.1, R527.2, R610.1, R613.1, R614.1, R617.1, U502.1 (GND), U502.3 (GND), U502.16 (GND), U502.17 (AGND_AUX), U502.32 (GND), U503.15 (GND), U504.2 (GND), U505.2 (GND); also elsewhere on the board
LEVELMETER: U503.27 (DC_ERR/MOUT); also elsewhere on the board
unnamed: C501.1, C604.1, U503.1 (GD1L)
unnamed: C502.1, C606.1, U503.3 (QD1G)
unnamed: C504.1, C613.1, U503.2 (GD1R)
unnamed: C504.2, C613.2, J601.2, R613.2
unnamed: C506.1, L505.1, U505.6 (SW)
unnamed: C506.2, U505.1 (CB)
unnamed: C508.1, C612.1, J602.1, L505.2, R518.1
unnamed: C509.2, U503.14 (CREF)
unnamed: C510.1, C603.1, U503.10 (FDL+)
unnamed: C511.1, C609.2, U503.11 (FDL-)
unnamed: C513.1, C610.2, U503.12 (FDR-)
unnamed: C514.1, C605.1, U503.13 (FDR+)
unnamed: C515.1, C537.1, J603.1, J603.5
unnamed: C515.2, C537.2, U503.21 (OUTLF)
unnamed: C516.1, C538.1, J603.3, J603.7
unnamed: C516.2, C538.2, U503.18 (OUTRF)
unnamed: C517.1, C539.1, J603.9
unnamed: C517.2, C539.2, U503.17 (OUTL2)
unnamed: C518.1, C540.1, J603.11
unnamed: C518.2, C540.2, U503.16 (OUTR2)
unnamed: C536.1, U503.22 (WIN_TC/VREF)
unnamed: J603.2, R618.2
unnamed: J603.4, R615.2
unnamed: J603.6, R616.2
unnamed: J603.8, R619.2
unnamed: J603.10, R620.2
unnamed: J603.12, R525.2
unnamed: Q501.1 (G), R514.1
unnamed: Q501.3 (D), R515.1, U502.8 (RSTN)
unnamed: R516.1, R518.2, U505.3 (FB)
unnamed: R522.1, U504.5 (ILIM)
unnamed: R522.2, R527.1
unnamed: R523.2, U503.26 (SDA)
unnamed: R524.2, U503.25 (SCL)
unnamed: TP501.1, U503.28 (WIN_IN/Beep)
unnamed: TP503.1, U503.23 (MUTE)
RST_BT: R513.2, R514.2; also elsewhere on the board
RxT: U502.10 (TX); also elsewhere on the board
SCL: R524.1; also elsewhere on the board
SDA: R523.1; also elsewhere on the board
SYSTEM_LOAD: C503.1, C505.2, U505.5 (VIN); also elsewhere on the board
TO_SPEAKER_L: R615.1, R617.2, R618.1; also elsewhere on the board
TO_SPEAKER_R: R20.2, R616.1, R619.1; also elsewhere on the board
TO_SUB: R525.1, R526.2, R620.1; also elsewhere on the board
TxR: U502.11 (RX); also elsewhere on the board

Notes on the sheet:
f_cutoff = 1/(100nF*100R) = 15.9kHz
Bluetooth Module
JW5026 TPS560430
Alternative: JOULWATT JW7111

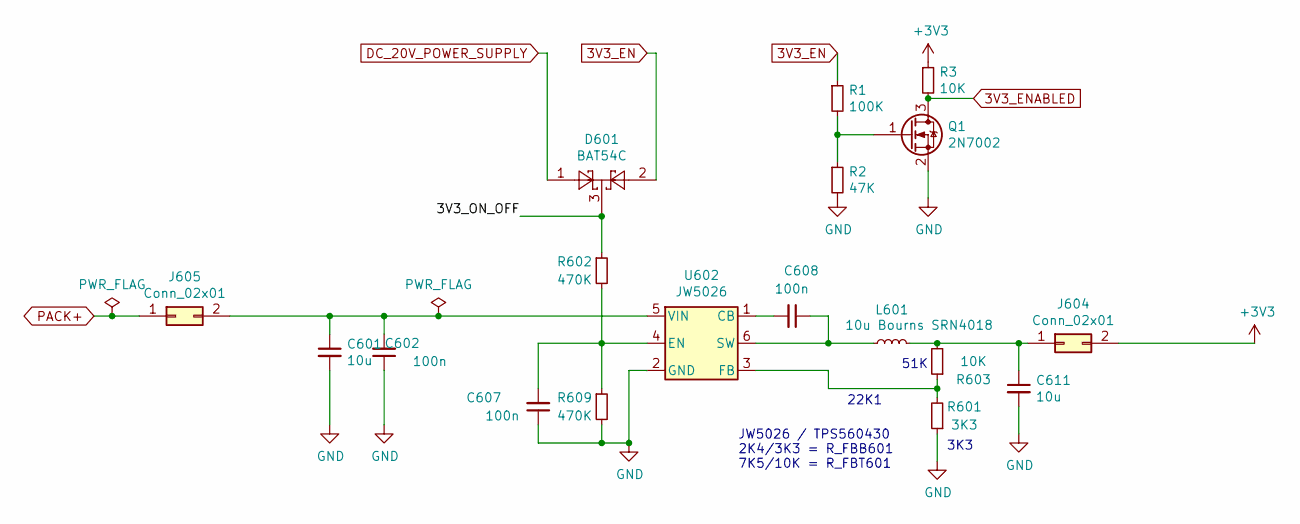
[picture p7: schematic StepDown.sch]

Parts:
C601, C611: 10u; C_1206_3216Metric_Pad1.42x1.75mm_HandSolder
C602, C607, C608: 100n; C_0603_1608Metric_Pad1.05x0.95mm_HandSolder
D601: BAT54C; SOT-23
J604, J605: Conn_02x01; PinHeader_1x02_P2.54mm_Vertical
L601: 10u Bourns SRN4018; L_Bourns-SRN4018
Q1: 2N7002; SOT-23
R1: 100K; R_0603_1608Metric_Pad1.05x0.95mm_HandSolder
R2: 47K; R_0603_1608Metric_Pad1.05x0.95mm_HandSolder
R3, R603: 10K; R_0603_1608Metric_Pad1.05x0.95mm_HandSolder
R601: 3K3; R_0603_1608Metric_Pad1.05x0.95mm_HandSolder
R602, R609: 470K; R_0603_1608Metric_Pad1.05x0.95mm_HandSolder
U602: JW5026; SOT-23-6_Handsoldering

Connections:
3V3_EN: D601.2, R1.1; also elsewhere on the board
3V3_ENABLED: Q1.3 (D), R3.2; also elsewhere on the board
/StepDown/3V3_ON_OFF: D601.3, R602.1
DC_20V_POWER_SUPPLY: D601.1; also elsewhere on the board
GND: C601.2, C602.1, C607.1, C611.2, Q1.2 (S), R2.2, R601.1, R609.2, U602.2 (GND); also elsewhere on the board
unnamed: C601.1, C602.2, J605.2, U602.5 (VIN)
unnamed: C607.2, R602.2, R609.1, U602.4 (EN)
unnamed: C608.1, L601.1, U602.6 (SW)
unnamed: C608.2, U602.1 (CB)
unnamed: C611.1, J604.1, L601.2, R603.2
unnamed: Q1.1 (G), R1.2, R2.1
unnamed: R601.2, R603.1, U602.3 (FB)
PACK+: J605.1; also elsewhere on the board

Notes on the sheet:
51K
22K1
JW5026 / TPS560430 2K4/3K3 = R_FBB601 7K5/10K = R_FBT601
3K3

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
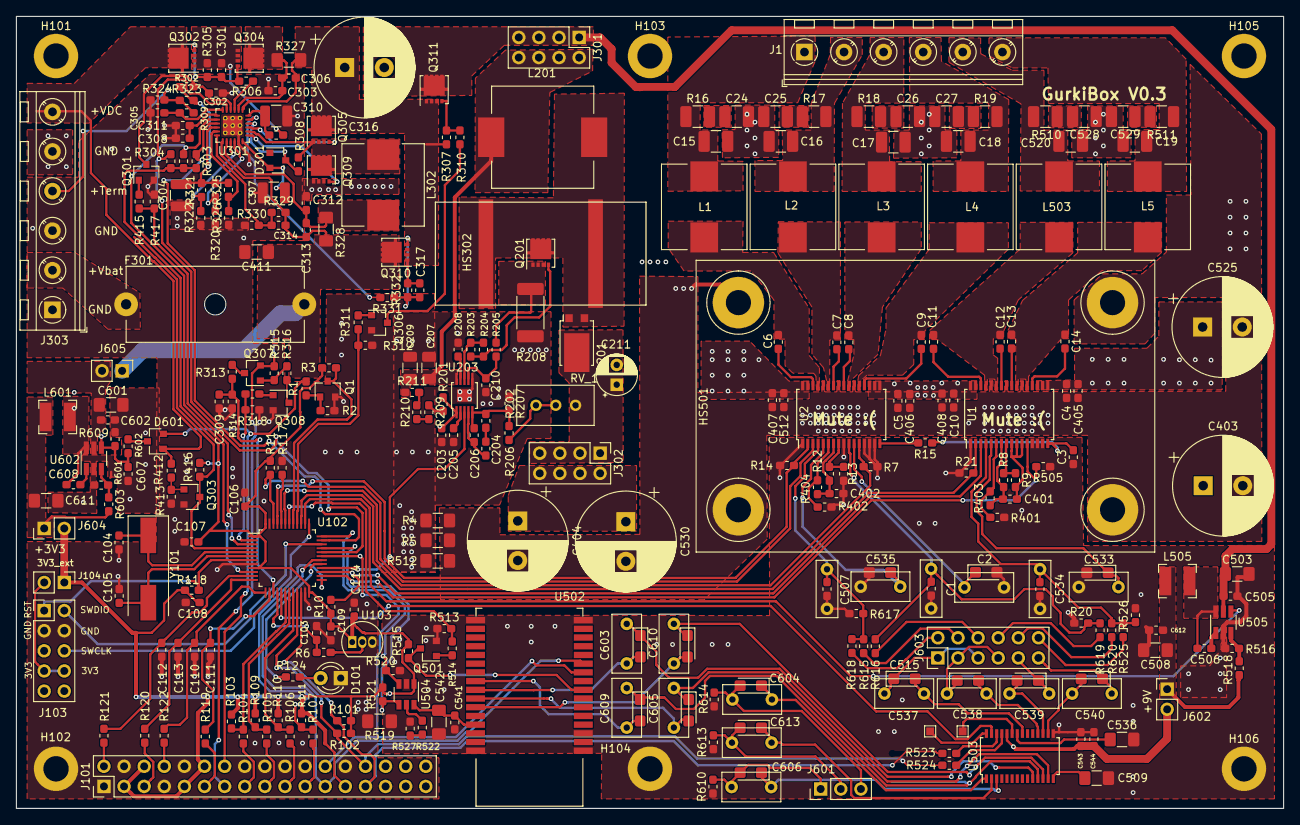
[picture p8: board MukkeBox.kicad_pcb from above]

Board: 2 copper layers, 160.0 x 100.0 mm, 309 parts (0 on the bottom side), 204 nets.

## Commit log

2020-03-19 Charger Fertig
    [00_StepUp.sch, 01_Charger.sch, 02_BMS.sch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]
2020-03-22 BMS fertig, Charger fertig, Amplifier fertig. TODO: Charge vs Discharge LiPo wie machen sachen
    [00_Charger.sch, 00_StepUp.sch, 01_BMS.sch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]
2020-03-22 LDO für Audio DSP hinzugefügt
    [00_Charger.sch, 01_BMS.sch, 02_StepUp.sch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]
2020-04-01 3v3 über LDO von BMS enablen. Bluetooth hinzugefügt
    [00_Charger.sch, 01_BMS.sch, 02_StepUp.sch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]
2020-04-06 power schalter und taser hinzugefügt. Selbsthaltung LDO hinzugefügt. Gain Potis hinzugefügt, Separater Ground für Audio Lines
    [Amplifier.sch, AudioProcessor.sch, Bluetooth.sch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]
2020-04-10 Schaltplan fertig. Fertig für review
    [00_Charger.sch, 01_BMS.sch, Amplifier.sch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]
2020-04-10 Footprintzuordnung angefangen
    [00_Charger.sch, 01_BMS.sch, 02_StepUp.sch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]
2020-04-11 fast alle footprints herausgesucht. Spulen typen rausgesucht: Bourns spulen
    [00_Charger.sch, 01_BMS.sch, 02_StepUp.sch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]
2020-04-11 Port Expander und Rotary Encoder hinzugefügt. TODO: Footprint Heatsink Amp
    [00_Charger.sch, 01_BMS.sch, 02_StepUp.sch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]
2020-04-12 PCB angefangen: Charger geplaced
    [00_Charger.sch, Amplifier.sch, AudioProcessor.sch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]
2020-04-12 Balancer geplaced
    [MukkeBox.kicad_pcb]
2020-04-12 Step Up geplaced
    [MukkeBox.kicad_pcb]
2020-04-12 Alle Parts geplaced: Dimension der Platine 200x105qmm. TODO Anzeige überarbeiten
    [02_StepUp.sch, MukkeBox.kicad_pcb, MukkeBox.sch]
2020-04-13 Mountingholes und Heatsinks hinzugefügt
    [01_BMS.sch, 02_StepUp.sch, MukkeBox.kicad_pcb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]
2020-04-13 fertig zum routen
    [00_Charger.sch, 01_BMS.sch, 02_StepUp.sch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]
2020-04-13 Amp verdrahtet, Einige Layers verlegt
    [Amplifier.sch, MukkeBox.kicad_pcb]
2020-04-14 Folienkondensatoren SMD gegen THT ausgetauscht. Kleine Fehler korrigiert
    [Amplifier.sch, Anzeige.sch, AudioProcessor.sch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]
2020-04-16 layout fast fertig
    [Amplifier.sch, AudioProcessor.sch, Bluetooth.sch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]
2020-04-17 PCB fertig verdrahtet
    [MukkeBox.kicad_pcb, MukkeBox.sch]
2020-04-17 Fertig zum letzten Check vor Bestellung
    [00_Charger.sch, 01_BMS.sch, 02_StepUp.sch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]
2020-04-18 Board abgeschickt
    [00_Charger.sch, 01_BMS.sch, 02_StepUp.sch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]
2020-04-30 PartPlaceHelper hinzugefügt
    [MukkeBox-B.Mask.dxf, MukkeBox-Edge.Cuts.dxf, MukkeBox-F.Mask.dxf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]
2020-05-23 Letzter Kommit Version 0.1, Branch für neues Layout 0.2
    [01_BMS.sch, MukkeBox.csv, MukkeBox.kicad_pcb]
2020-05-24 mute and stdby tda7498 geändert, tda7418 durch tda7719 ersetzt, xs3868 durch bk8000l ersetzt, 3v3 stepdown statt LDO. BMS gelöscht. TODO: Möglichkeit stepup und stepdown als modul aufzusetzen
    [00_Charger.sch, 02_StepUp.sch, Amplifier.sch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]
2020-05-24 neue schematic fertig zum rewiew. DRC clean
    [00_Charger.sch, 02_StepUp.sch, Amplifier.sch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]
2020-05-24 module, falls schaltung nicht funktioniert hinzugefügt
    [02_StepUp.sch, AudioProcessor.sch, MukkeBox.sch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]
2020-05-25 3v3 regler ändern
    [00_Charger.sch, Amplifier.sch, AudioProcessor.sch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]
2020-05-25 TODO: power on detect einfügen
    [00_Charger.sch, AudioProcessor.sch, MukkeBox.kicad_pcb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]
2020-05-25 3v3 regler layout fertig
    [00_Charger.sch, 02_StepUp.sch, MukkeBox.kicad_pcb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]
2020-05-28 vor änderungen von der Arbeit
    [00_Charger.sch, 00_StepUp.sch, 01_BMS.sch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]
2020-05-28 Nach Änderungen auf der Arbeit + anderes
    [Amplifier.sch, AudioProcessor.sch, MukkeBox-B.Mask.dxf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]
2020-06-02 Charger austauschen gegen bq24610
    [00_Charger.sch, 02_StepUp.sch, Amplifier.sch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]
2020-06-02 Charger ausgetauscht, Mosfet und Dioden durch billigere ersetzt
    [00_Charger.sch, 02_StepUp.sch, Amplifier.sch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]
2020-06-03 Änderungen Arbeit hinzugefügt: Layout neuer Charger
    [00_Charger.sch, 02_StepUp.sch, Amplifier.sch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]
2020-06-03 Layout fertig, Schaltplan erneut checken
    [00_Charger.sch, 02_StepUp.sch, Amplifier.sch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]
2020-06-04 Änderungen von der Arbeit, Viele LCSC Teile für teurere ausgetauscht
    [00_Charger.sch, 02_StepUp.sch, Amplifier.sch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]
2020-06-06 Fast fertig TODO: Connector umverdrahten mit beschriftung
    [00_Charger.sch, 00_StepUp.sch, 01_BMS.sch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]
2020-06-06 Bestellung abgeschickt
    [00_Charger.sch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]
2020-06-07 Bauteilwerte verändert
    [02_StepUp.sch, AudioProcessor.sch, MukkeBox.kicad_pcb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]
2020-06-29 Fehler bei Bestellung behoben: größere Vias. Platinen erfolgreich erhalten
    [00_Charger.sch, 02_StepUp.sch, Amplifier.sch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]
2020-07-10 Bereit zur Bestellung
    [00_Charger.sch, 02_StepUp.sch, Amplifier.sch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]
2020-07-10 Platine in X um 25mm verkürzt
    [00_Charger.sch, 02_StepUp.sch, MukkeBox.kicad_pcb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]
2020-07-12 MukkePlatine auf EuroPlatinen groesse geändert
    [00_Charger.sch, 02_StepUp.sch, Amplifier.sch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]
2020-07-12 fertig zum bestellen
    [MukkeBox.kicad_pcb]
2020-07-13 Footprints parallel zu Folienkondensatoren hinzugefügt; Bestellung ist abgeschickt!
    [00_Charger.sch, 02_StepUp.sch, Amplifier.sch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]
2020-10-24 I2C Dreher behoben, BOM vereinfacht, 20dB Gain an ClassD Amps
    [00_Charger.sch, 02_StepUp.sch, Amplifier.sch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]
